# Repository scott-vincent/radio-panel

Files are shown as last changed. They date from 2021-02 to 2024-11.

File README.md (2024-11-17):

# MICROSOFT FLIGHT SIMULATOR 2020 - RADIO PANEL

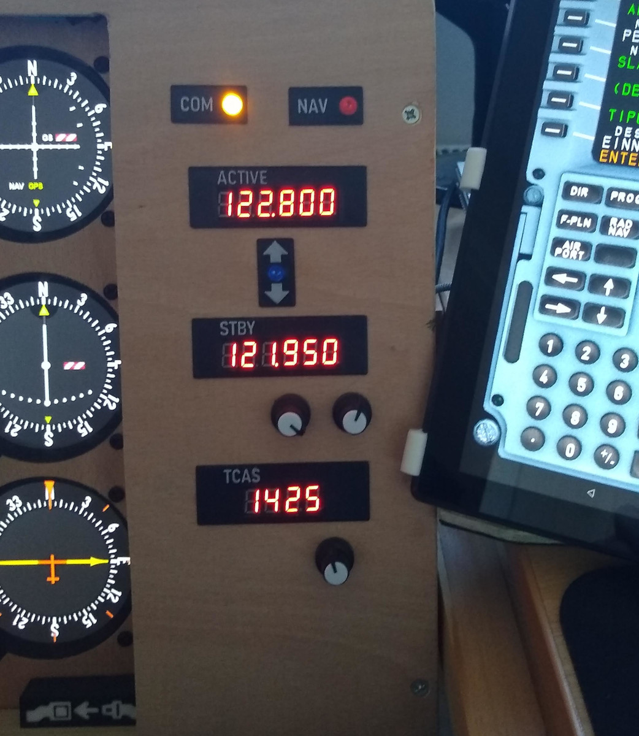
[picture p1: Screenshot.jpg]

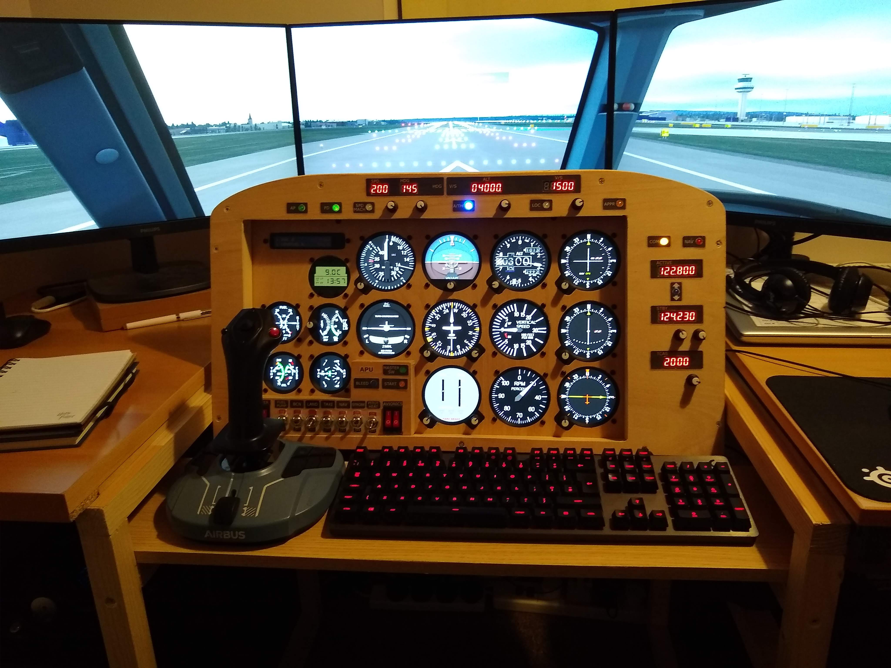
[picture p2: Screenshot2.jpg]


# Quick Start

Download the following two files.

Link: [Latest release of Radio Panel for Raspberry Pi Zero W](https://github.com/scott-vincent/radio-panel/releases/latest/download/radio-panel-v1.5.5-raspi.tar.gz)

Link: [Latest release of Instrument Data Link for Windows](https://github.com/scott-vincent/instrument-data-link/releases/latest/download/instrument-data-link-v2.0.5-windows-x64.zip)

Unzip instrument-data-link into its own folder and double-click instrument-data-link.exe to run it.

Untar radio-panel on your Raspberry Pi. Edit settings/radio-panel.json and in the "Data Link" section change the IP address of the "Host" to the address where FS2020 is running on your local network, e.g. 192.168.0.1 - You can find the correct address of your host by running a command prompt on the host machine and running ipconfig, then scroll back and look for the first "IPv4 Address" line. Now enter ./run.sh to run the program.

# Introduction

A radio panel for MS FlightSim 2020. This program is designed to run
on a Raspberry Pi Zero W and requires the following hardware:

8 digit 7-segment display x 3 : https://www.amazon.co.uk/gp/product/B087BSH26N  

Push button with LED x 3 : https://www.amazon.co.uk/gp/product/B07KPSZ731 

Rotary encoder x 3 : https://www.amazon.co.uk/gp/product/B07FYHG2QZ  

It requires the companion program from here

  https://github.com/scott-vincent/instrument-data-link

The companion program runs on the same host as MS FS2020 and passes data between
the panel and the flight simulator over your Wifi connection.

# Donate

If you find this project useful, would like to see it developed further or would just like to buy the author a beer, please consider a small donation.

[](https://paypal.me/scottvincent2020)

# Additional Photos

Panel Front
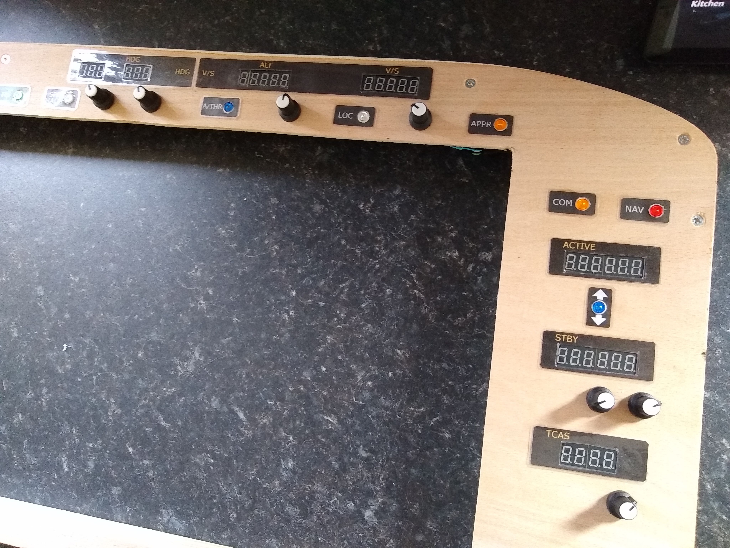
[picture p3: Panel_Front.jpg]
Panel Front


Panel Back
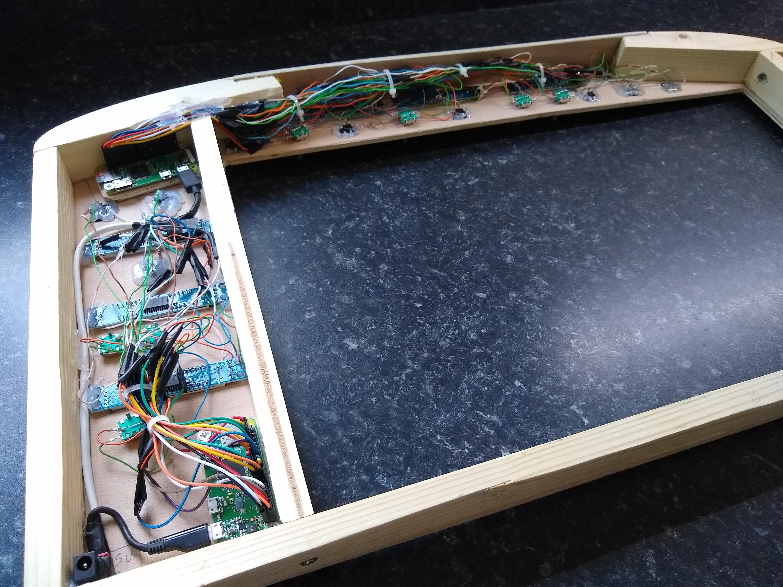
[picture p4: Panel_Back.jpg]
Panel Back


Panel Pi Zeroes
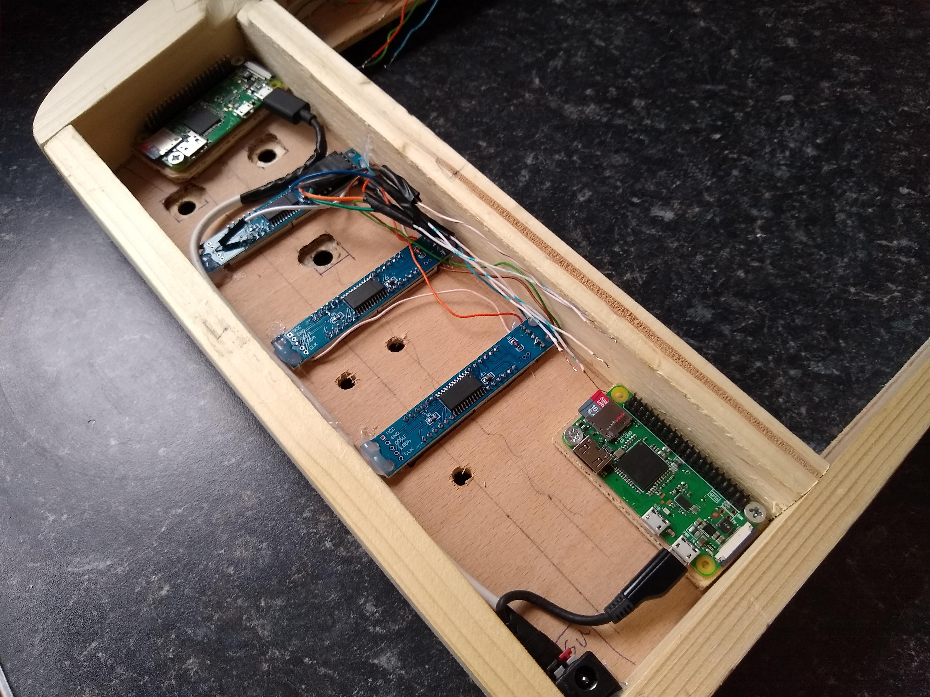
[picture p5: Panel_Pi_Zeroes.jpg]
Panel Wiring


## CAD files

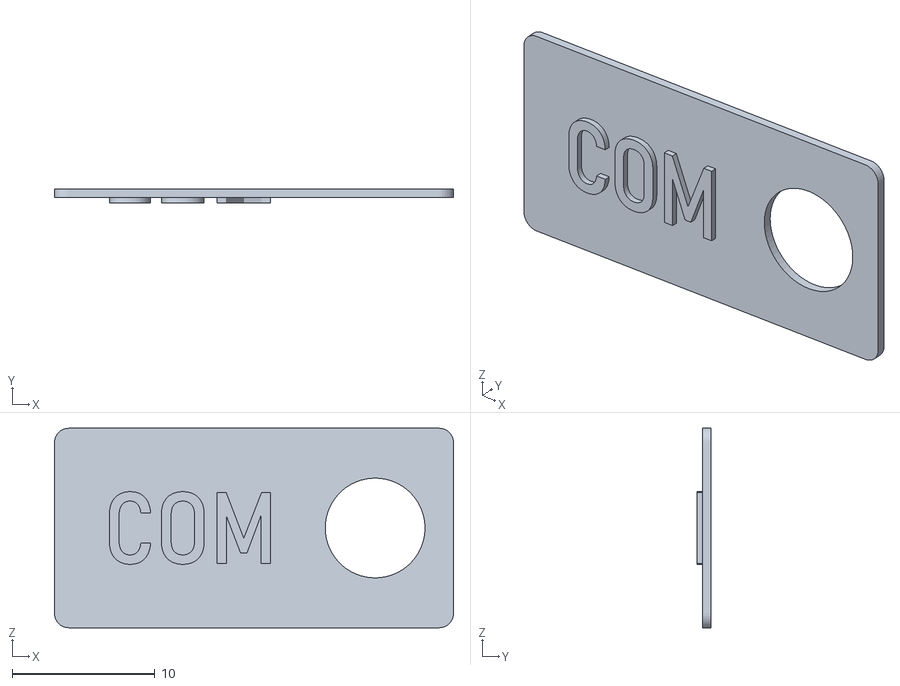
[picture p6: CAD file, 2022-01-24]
3D Printed Labels/Radio Com.stl
28.0 x 1.00 x 14.0

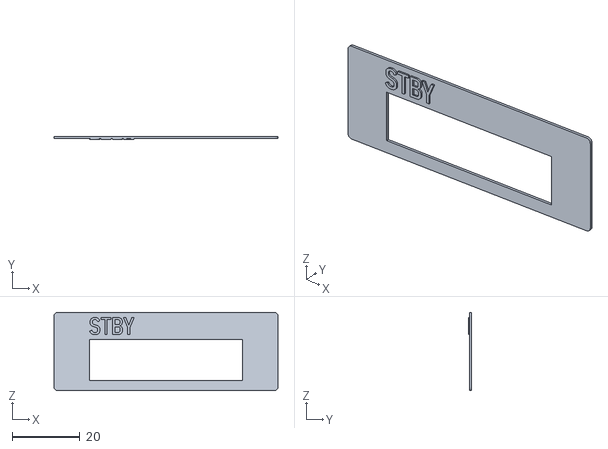
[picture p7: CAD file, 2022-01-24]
3D Printed Labels/Radio Standby.stl
66.0 x 1.00 x 23.0

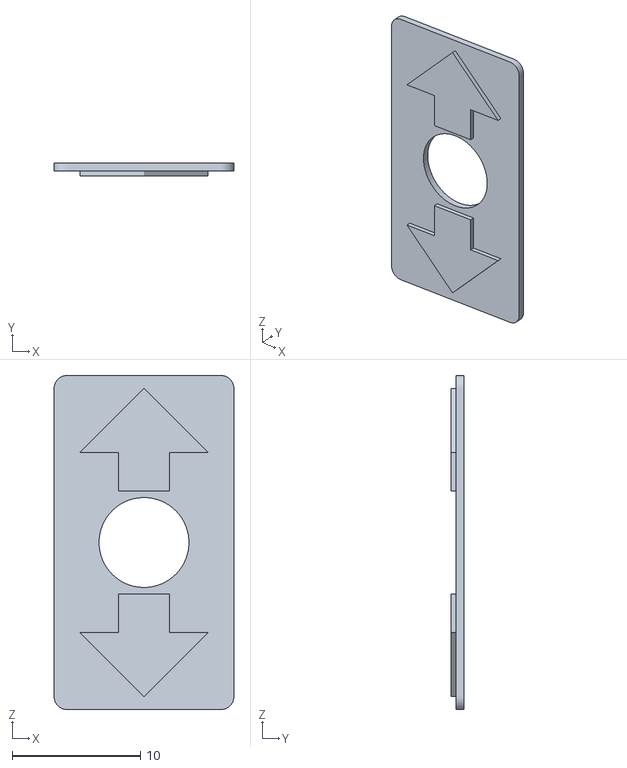
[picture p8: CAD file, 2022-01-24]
3D Printed Labels/Radio Swap.stl
14.0 x 1.00 x 26.0

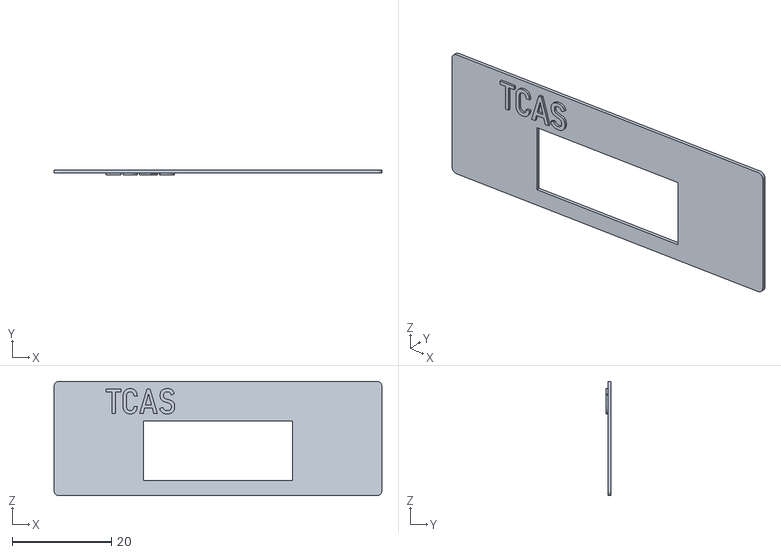
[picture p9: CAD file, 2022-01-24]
3D Printed Labels/Radio TCAS.stl
66.0 x 1.00 x 23.0

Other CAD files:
3D Printed Labels/Radio Active.stl
3D Printed Labels/Radio Nav.stl

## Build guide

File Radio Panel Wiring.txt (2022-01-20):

3 x 8 digit 7-segment displays

Requires the following line in /boot/config.txt: dtoverlay=spi0-1cs,no_miso

Orange		3.3v		Pin 1
Blue		Gnd		Pin 6
White		DIN		Pin 19
Brown		CS		Pin 24
Green		CLK		Pin 23

3 x Rotary switches

Brown		Gnd			Pin 6
Green/White	Rotary 1		Pin a
Orange		Rotary 2		Pin b
Blue		Push			Pin c

		a			b			c
Freq Whole	Pin 3	GPIO 2		Pin 5	GPIO 3
Freq Fraction	Pin 11	GPIO 17		Pin 13	GPIO 27		Pin 15	GPIO 22
Squawk		Pin 16	GPIO 23		Pin 18	GPIO 24		Pin 21	GPIO 9

3 x Buttons (no Led for swap)

White		Gnd			Pin 6
Blue/Green	Push			Pin a
Orange/Brown	Led			Pin b

		a			b			LED Colour
Swap		Pin 37	GPIO 26
Com		Pin 38	GPIO 20		Pin 40	GPIO 21		Yellow
Nav		Pin 32	GPIO 12		Pin 36	GPIO 16		Red

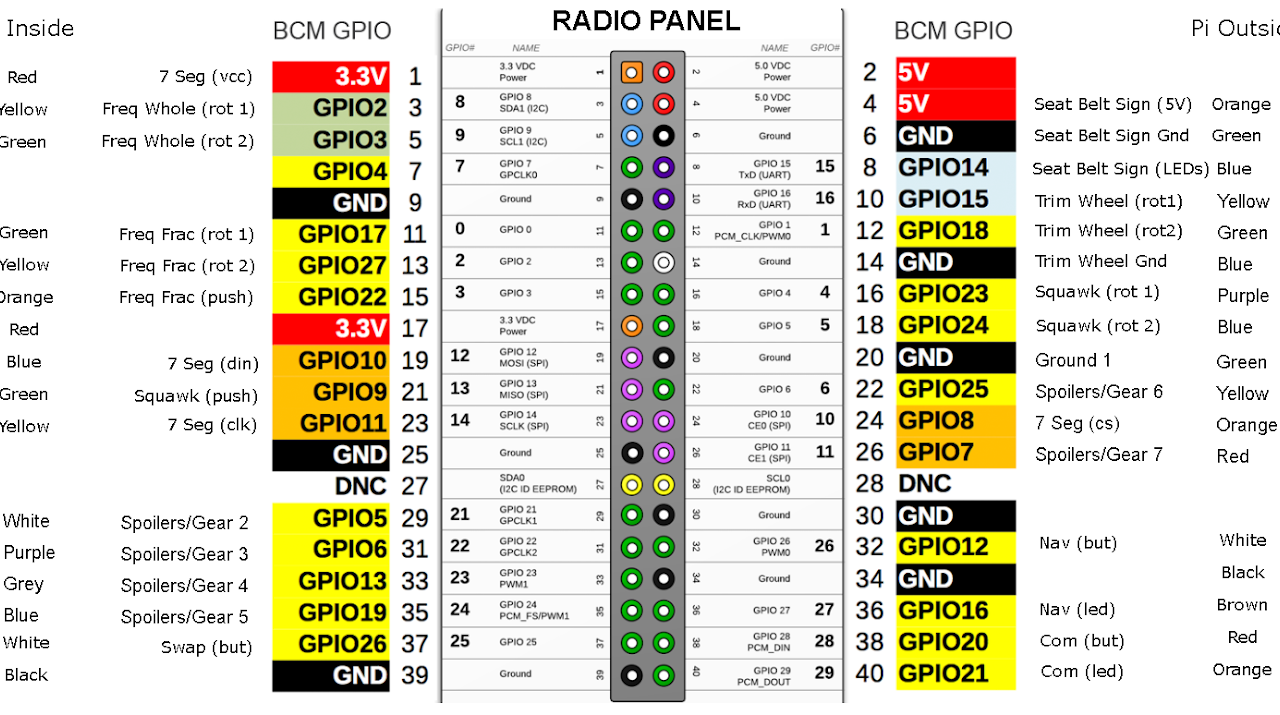
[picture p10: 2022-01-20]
Radio Panel Wiring.png

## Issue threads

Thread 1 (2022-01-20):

Wiring diagramm for raspi zeroW/Radio panel

MartinKrause57, 2022-01-20:
Hallo
I found your Github-project and want to build the radio-panel.
I have the programm installed on a Raspberry zero. I buy the comonents and want to install. But i have a problem to find the Pins on the raspberry. It´s possible to give me a wiring diagramm. On the pictures i don´t see not enough.
Thanks
Martin Krause

scott-vincent, 2022-01-20:
Hi Martin,

I've added 'Radio Panel Wiring.png' and 'Radio Panel Wiring.txt' to this repository. It shows some of my additional hardware that connects to that Pi (seatbelt sign, spoilers etc) which you can just ignore.

scott-vincent, 2022-01-20:
Note that the 7-seg displays are daisy chained so only the first one (or is it the last one?) is connected to the Pi.

MartinKrause57, 2022-01-20:
Hallo Scott

Thank you for this information. I change the config.txt and i see the frequenz.

The display was the first one. So i connect the other display to the pins which i see on the screen when i start the radio-panel.

Thank you for help.

Martin

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

Closed 2022-01-21.

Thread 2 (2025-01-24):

Selecting COM1/2 Nav1/2 ADF

8ValveLabs, 2025-01-24:
Hi there looking through the code I see that there's a case switch for determining if COM1/2 or NAV1/2 or ADF is selected based on aircraft type it seems.

Is there a simple way to switch between COM1/2 NAV1/2 & ADF? I'm looking to control all of those with just one panel. If not, maybe I could contribute this feature? I would add maybe 5 simple push buttons labelled COM1, COM2, NAV1, NAV2, ADF storing the selected mode in a variable, and switch the case based off that instead of aircraft type?

scott-vincent, 2025-01-24:
You just use the Com and Nav clickable buttons.

If you currently have COM1 or COM2 selected then pressing the NAV button switches to NAV1. If you press it a 2nd time it switches to NAV2 and if you press it a 3rd time it switches to ADF. When you have NAV selected, pushing the COM button switches to COM1 and pushing it a 2nd time switches to COM2.

This is the code that does it:

            // If showing COM, show NAV1
            if (!showNav) {
                showNav = true;
                globals.gpioCtrl->writeLed(comControl, !showNav);
                globals.gpioCtrl->writeLed(navControl, showNav);
            }
            else {
                // Already showing NAV so switch between NAV1, NAV2 and ADF

8ValveLabs, 2025-01-24:
@scott-vincent sincerely, thank you for this, I knew I was missing something! Sent a donation your way, really appreciate the work done on this.

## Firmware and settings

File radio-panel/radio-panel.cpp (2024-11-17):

/*
 * Flight Simulator Radio Panel
 * Copyright (c) 2023 Scott Vincent
 */

#include <stdio.h>
#include <stdlib.h>
#include <unistd.h>
#include <wiringPi.h>
#include "gpioctrl.h"
#include "globals.h"
#include "settings.h"
#include "simvars.h"
#include "radio.h"

const char* radioVersion = "v1.5.5";
const bool Debug = false;

struct globalVars globals;

radio* rad;

/// <summary>
/// Initialise
/// </summary>
void init(const char *settingsFile = NULL)
{
    // Init wiringPi ourselves as it is needed by both
    // gpioCtrl and sevenSegment.
    wiringPiSetupGpio();

    globals.allSettings = new settings(settingsFile);
    globals.simVars = new simvars();
    globals.gpioCtrl = new gpioctrl(false);
}

/// <summary>
/// Fetch latest values of common variables
/// </summary>
void updateCommon()
{
    SimVars* simVars = &globals.simVars->simVars;

    // Electrics check
    if (globals.aircraft == FBW) {
        // Radio only comes on if both batteries on or
        // have external power, APU or main engines running.
        globals.electrics = globals.connected && (simVars->dcVolts > 25.4 ||
            (simVars->elecBat1 > 0 && simVars->elecBat2 > 0));
    }
    else if (globals.aircraft == AIRBUS_A310) {
        globals.electrics = globals.connected && simVars->batteryLoad < 0;
    }
    else {
        globals.electrics = globals.connected && simVars->dcVolts > 0;
    }

    // Avionics check
    globals.avionics = globals.connected && (simVars->com1Status == 0 || simVars->com2Status == 0);
}

/// <summary>
/// Update everything before the next frame
/// </summary>
void doUpdate()
{
    updateCommon();

    rad->update();
}

///
/// main
///
int main(int argc, char **argv)
{
    printf("radio-panel %s\n", radioVersion);
    fflush(stdout);

    if (argc > 1) {
        init(argv[1]);
    }
    else {
        init();
    }

    rad = new radio();

    while (!globals.quit) {
        doUpdate();
        rad->render();

        // Update 10 times per second
        usleep(100000);
    }

    return 0;
}

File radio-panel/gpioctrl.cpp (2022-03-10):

#include <stdio.h>
#include <stdlib.h>
#include <cstring>
#include <set>
#include <wiringPi.h>
#include "settings.h"
#include "gpioctrl.h"

const char* GpioGroup = "GPIO";
const char* RotaryEncoderGroup = "RotaryEncoder";   // Rot1, Rot2, Push
const char* ButtonGroup = "Button";                 // Push, Led
const char* SwitchGroup = "Switch";                 // Toggle, Led
const char* LampGroup = "Lamp";                     // Led

// SPI GPIO pins
const int SPI_MOSI = 10;
const int SPI_SCLK = 11;
const int SPI_CE0 = 8;

void watcher(gpioctrl*);

gpioctrl::gpioctrl(bool initWiringPi)
{
    // Caller may want to initialise wiringPi themselves
    if (initWiringPi) {
        // Use BCM GPIO pin numbers
        wiringPiSetupGpio();
    }

    // Reserve pins for SPI channel 0 with no MISO
    printf("Added SPI CE0 with no MISO: GPIO%d, GPIO%d, GPIO%d\n", SPI_MOSI, SPI_SCLK, SPI_CE0);

}

gpioctrl::~gpioctrl()
{
    if (watcherThread) {
        // Wait for thread to exit
        watcherThread->join();
    }
}

int gpioctrl::getSetting(const char* controlName, const char *controlType, const char *attribute)
{
    char settingGroup[256];

    sprintf(settingGroup, "%s/%s/%s", GpioGroup, controlName, controlType);
    return globals.allSettings->getInt(settingGroup, attribute);
}

int gpioctrl::addControl()
{
    if (controlCount >= MaxControls) {
        printf("Maximum number of GPIO controls exceeded\n");
        exit(1);
    }

    int num = controlCount;
    controlCount++;

    gpio[num][Rot1] = INT_MIN;
    gpio[num][Rot2] = INT_MIN;
    gpio[num][Push] = INT_MIN;
    gpio[num][Toggle] = INT_MIN;
    gpio[num][Led] = INT_MIN;

    rotateValue[num] = 0;
    pushValue[num] = 0;
    toggleValue[num] = 1;   // Default to high (off)
    lastRotateValue[num] = -1;
    lastPushValue[num] = -1;
    lastRotateState[num] = -1;
    lastPushState[num] = -1;
    clockwise[num] = true;

    return num;
}

void gpioctrl::validateControl(const char* controlName, int control)
{
    std::set<int> usedPins;

    // Reserve SPI pins
    usedPins.insert(SPI_MOSI);
    usedPins.insert(SPI_SCLK);
    usedPins.insert(SPI_CE0);

    // Find all pins already in use
    for (int num = 0; num < controlCount; num++) {
        if (num != control) {
            if (gpio[num][Rot1] != INT_MIN) usedPins.insert(gpio[num][Rot1]);
            if (gpio[num][Rot2] != INT_MIN) usedPins.insert(gpio[num][Rot2]);
            if (gpio[num][Push] != INT_MIN) usedPins.insert(gpio[num][Push]);
            if (gpio[num][Toggle] != INT_MIN) usedPins.insert(gpio[num][Toggle]);
            if (gpio[num][Led] != INT_MIN) usedPins.insert(gpio[num][Led]);
        }
    }
    
    // Make sure at least one pin specified
    if (gpio[control][Rot1] == INT_MIN && gpio[control][Rot2] == INT_MIN
        && gpio[control][Push] == INT_MIN && gpio[control][Toggle] == INT_MIN
        && gpio[control][Led] == INT_MIN) {
        printf("Cannot add %s control as no settings specified (or wrong control type specified in addGpio method)\n", controlName);
        exit(1);
    }

    // Make sure new pins are unique
    if (usedPins.find(gpio[control][Rot1]) != usedPins.end()) {
        printf("Duplicate GPIO pin number specified for %s/Rot1\n", controlName);
        exit(1);
    }

    if (usedPins.find(gpio[control][Rot2]) != usedPins.end()) {
        printf("Duplicate GPIO pin number specified for %s/Rot2\n", controlName);
        exit(1);
    }

    if (usedPins.find(gpio[control][Push]) != usedPins.end()) {
        printf("Duplicate GPIO pin number specified for %s/Push\n", controlName);
        exit(1);
    }

    if (usedPins.find(gpio[control][Toggle]) != usedPins.end()) {
        printf("Duplicate GPIO pin number specified for %s/Toggle\n", controlName);
        exit(1);
    }

    if (usedPins.find(gpio[control][Led]) != usedPins.end()) {
        printf("Duplicate GPIO pin number specified for %s/Led\n", controlName);
        exit(1);
    }
}

int gpioctrl::addRotaryEncoder(const char *controlName)
{
    int newControl = addControl();

    gpio[newControl][Rot1] = getSetting(controlName, RotaryEncoderGroup, "Rot1");
    gpio[newControl][Rot2] = getSetting(controlName, RotaryEncoderGroup, "Rot2");
    gpio[newControl][Push] = getSetting(controlName, RotaryEncoderGroup, "Push");

    char msg[256];
    if (gpio[newControl][Rot1] != INT_MIN && gpio[newControl][Rot2] != INT_MIN) {
        initPin(gpio[newControl][Rot1], true);
        initPin(gpio[newControl][Rot2], true);
        sprintf(msg, "Added %s rotary encoder: GPIO%d, GPIO%d",
            controlName, gpio[newControl][Rot1], gpio[newControl][Rot2]);
    }
    else if (gpio[newControl][Rot1] != INT_MIN || gpio[newControl][Rot2] != INT_MIN) {
        printf("Must specify both Rot1 and Rot2 (or neither) for control: %s\n", controlName);
        exit(1);
    }
    else {
        msg[0] = '\0';
    }

    if (gpio[newControl][Push] != INT_MIN) {
        initPin(gpio[newControl][Push], true);
        if (msg[0] == '\0') {
            sprintf(msg, "Added %s rotary encoder push: GPIO%d", 
                controlName, gpio[newControl][Push]);
        }
        else {
            char addMsg[256];
            sprintf(addMsg, " with push: GPIO%d", gpio[newControl][Push]);
            strcat(msg, addMsg);
        }
    }

    if (msg[0] != '\0') {
        printf("%s\n", msg);
    }

    validateControl(controlName, newControl);
    return newControl;
}

int gpioctrl::addButton(const char* controlName)
{
    int newControl = addControl();

    gpio[newControl][Push] = getSetting(controlName, ButtonGroup, "Push");
    gpio[newControl][Led] = getSetting(controlName, ButtonGroup, "Led");

    char msg[256];
    if (gpio[newControl][Push] != INT_MIN) {
        initPin(gpio[newControl][Push], true);
        sprintf(msg, "Added %s button: GPIO%d", controlName, gpio[newControl][Push]);
    }
    else {
        msg[0] = '\0';
    }

    if (gpio[newControl][Led] != INT_MIN) {
        initPin(gpio[newControl][Led], false);
        if (msg[0] == '\0') {
            sprintf(msg, "Added %s led: GPIO%d", controlName, gpio[newControl][Led]);
        }
        else {
            char addMsg[256];
            sprintf(addMsg, " with led: GPIO%d", gpio[newControl][Led]);
            strcat(msg, addMsg);
        }
    }

    if (msg[0] != '\0') {
        printf("%s\n", msg);
    }

    validateControl(controlName, newControl);
    return newControl;
}
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

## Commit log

2021-02-08 Make leds more responsive
2021-03-07 Fix hard reset false trigger
    [radio.cpp, radio.h]
2021-03-14 Add elevator trim wheel
2021-04-09 Fix landing gear
2021-07-28 Add a32nx park brake
2021-08-03 Fix parking brake
2021-08-23 Add brake position
2021-08-26 Fix B747 squawk code bug
    [radio.cpp, radio.h]
2021-08-26 Fix various B747 bugs
    [radio.cpp, radio.h]
2021-08-26 Force COM2 on B747 due to bug
    [radio.cpp]
2021-10-15 Add both brake pedals
2021-11-28 Show landing rate
2022-01-03 Fix landing rate
2022-01-20 Add wiring diagram
2022-01-24 Add 3d printed labels
    [Radio Active.stl, Radio Com.stl, Radio Nav.stl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]
2022-03-15 Fix delta data corruption
    [radio.cpp, radio.h]
2023-04-23 Add ADF audio button
2024-11-17 Fix G1000 managed heading
    [radio-panel.cpp, radio.cpp]
